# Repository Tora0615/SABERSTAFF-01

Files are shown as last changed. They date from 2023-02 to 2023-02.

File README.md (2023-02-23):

# SABERSTAFF-01

利用 attiny 85 與 433 mhz 無線收發模組製作的 ARGB 表演用光棍，解決不同裝置與電腦間的同步問題，實現了配合音樂節奏的卡點燈光表演。

The ARGB light rod made with attiny85 and 433 mhz wireless module. It solves the synchronization problem (e.g. music doesn't match the light) between different devices and computers. This made it can perform light show perfectly with music rhythm.

# Structure and how it work

```
--- PC ---

1. When Press the run button 
   |----> 2. Countdown ----> 7. Play music (Light Show will start at the same time)
   |----> 2. send reset signal via serial ----> Arduino nano + 433 mHz send module
                                                                    |
                                                                    |--> 3. send reset signal

--- SABERSTAFF ---

|---| 5. Self Reboot
|   |
|   ∨
-- attiny 85 <------- 433 mHz receive module (4. send a reset signal when receive data)
    |
    ∨
    6. Countdown
    |
    ∨
    7. Start the Light Show (Music will start at the same time)

```

# Design
## Hardware
### Schematic
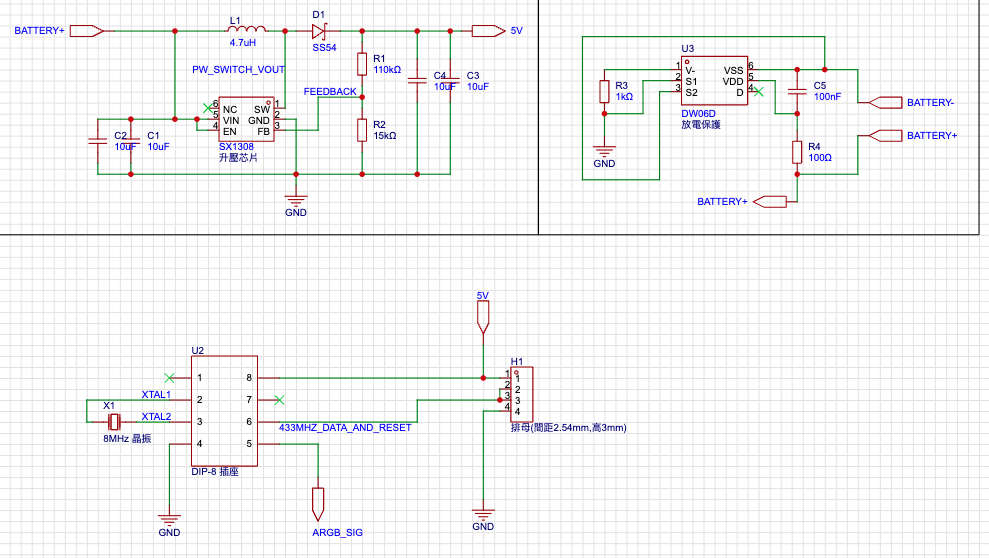
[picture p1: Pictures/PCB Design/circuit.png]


### PCB Design in 2D
<p float="left">
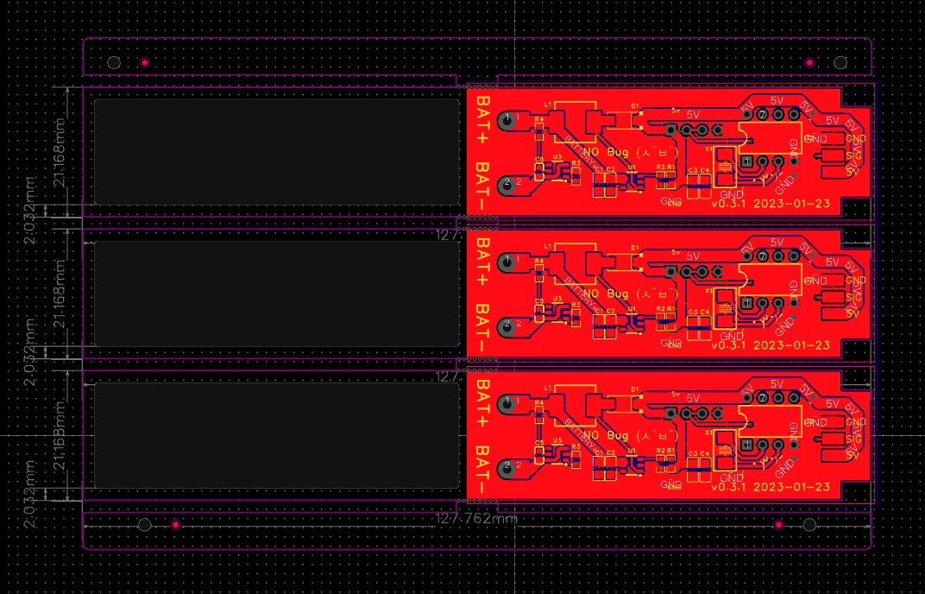
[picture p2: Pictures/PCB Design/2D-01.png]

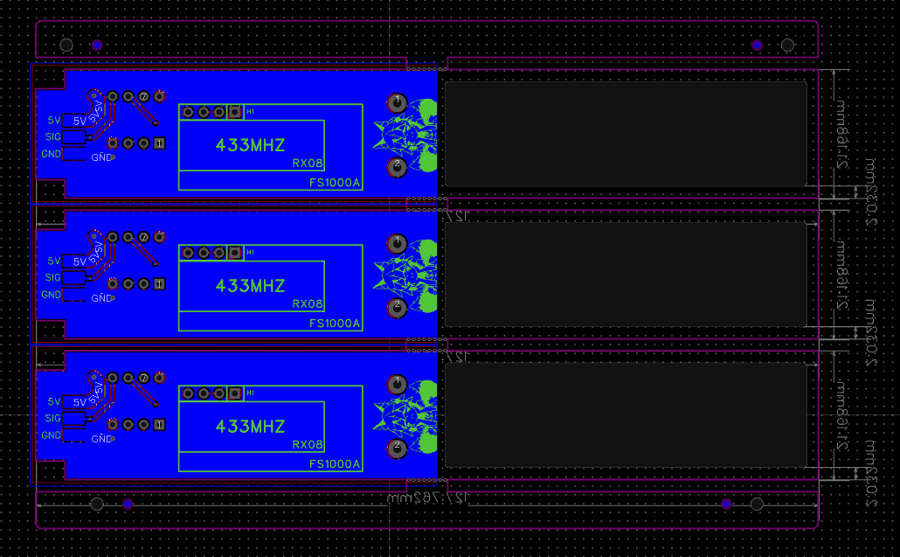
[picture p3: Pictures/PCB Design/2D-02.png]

</p>

### PCB Design in 3D
<p float="left">
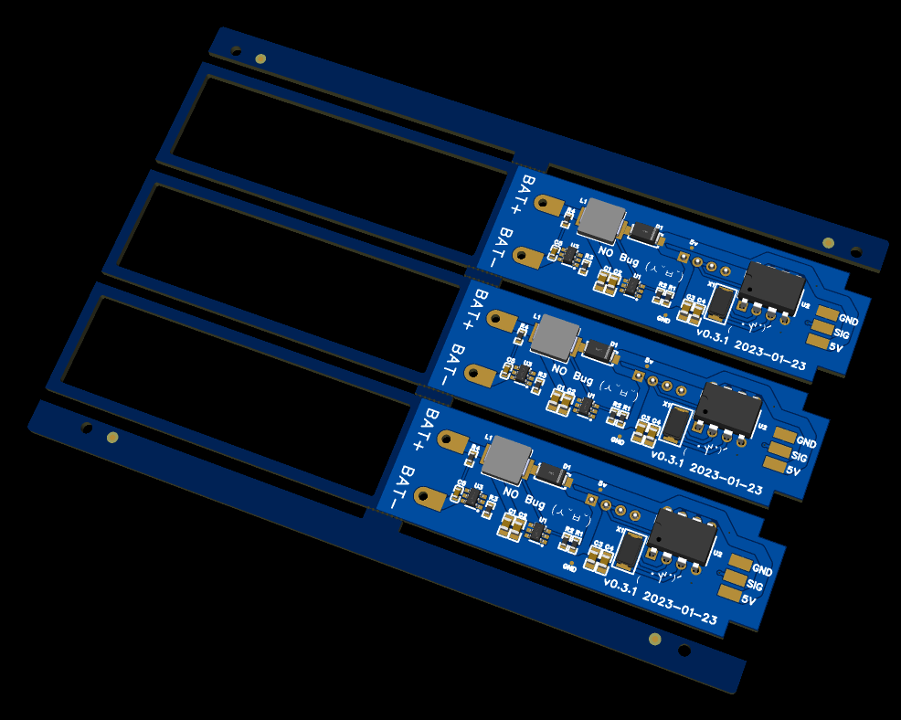
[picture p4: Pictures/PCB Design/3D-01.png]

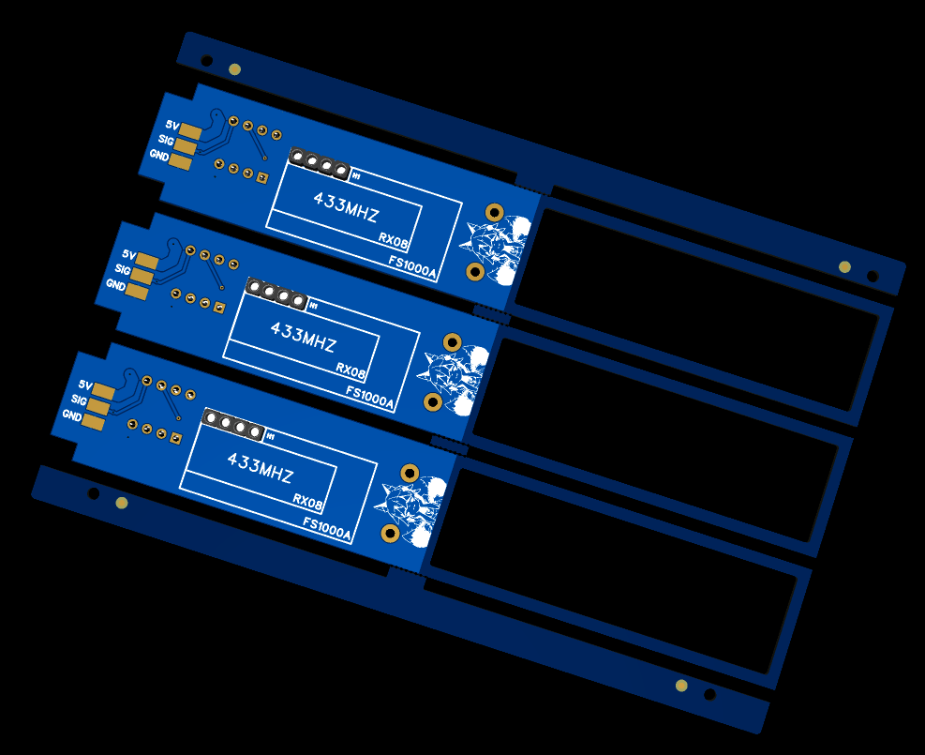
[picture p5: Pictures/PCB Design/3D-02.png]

</p>

### Real PCB 
<p float="left">
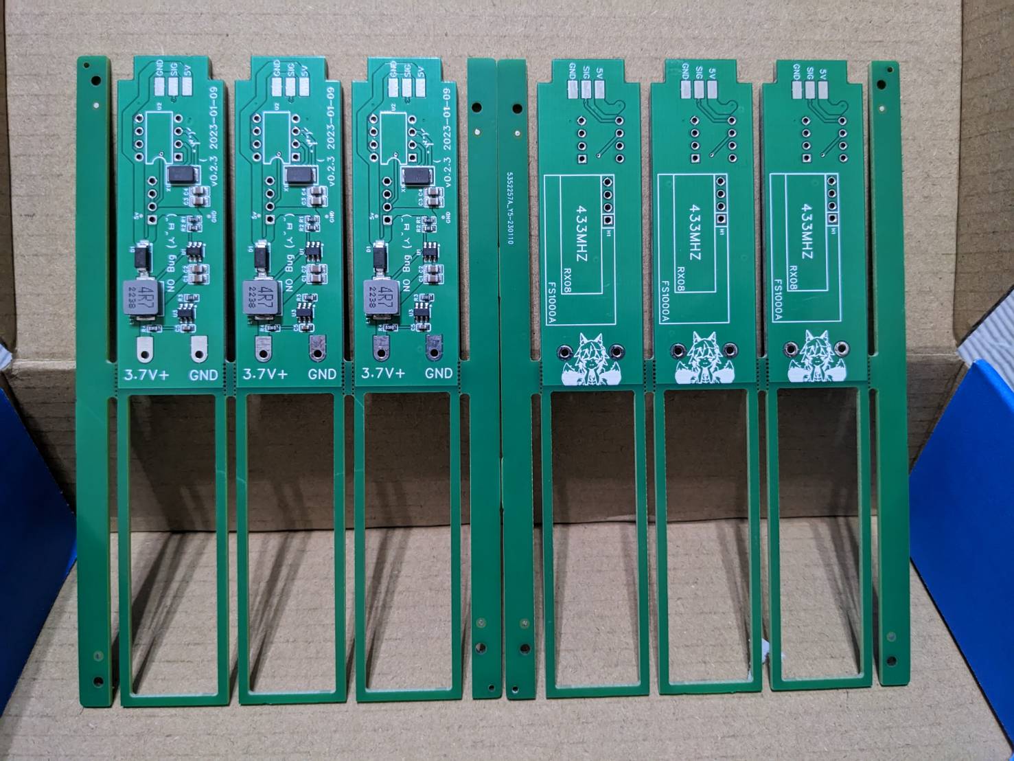
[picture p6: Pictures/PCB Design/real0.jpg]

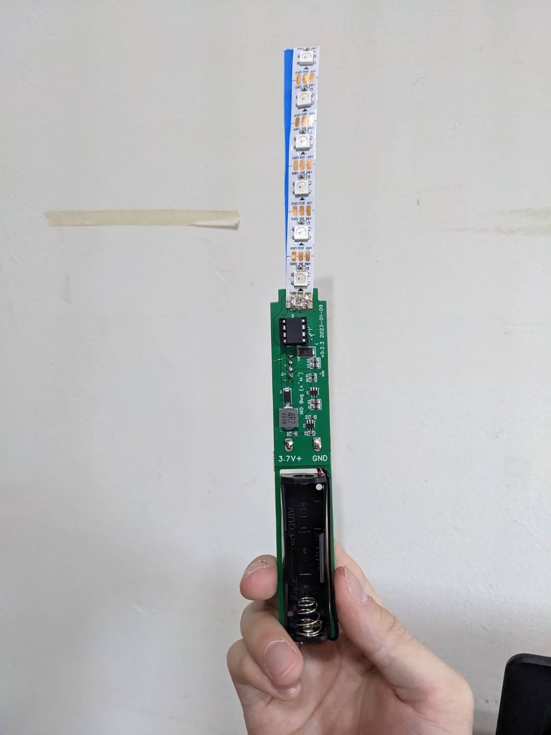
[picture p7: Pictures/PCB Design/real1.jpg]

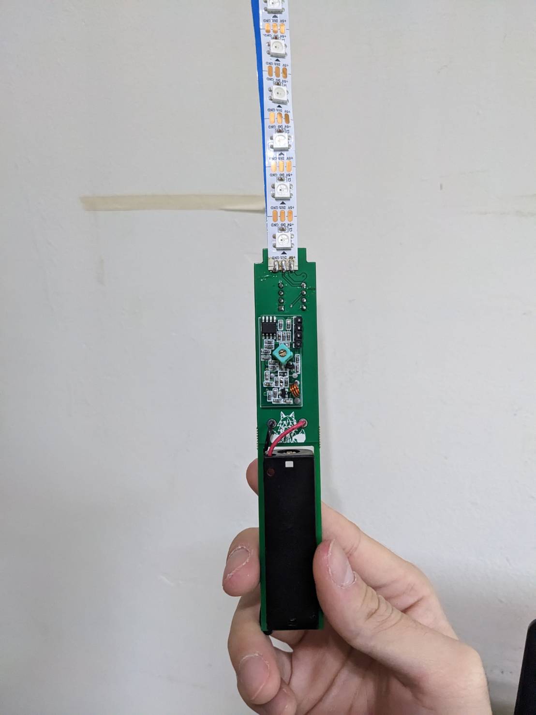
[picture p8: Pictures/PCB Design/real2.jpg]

</p>

### The finished product

fire

## Software

* Folder - PcControlArduino
  * python_control_arduino.py - control arduino via serial and control music playing at the same time.
* Folder - 433mhzDataSender_nano_ver
  * 433mhzDataSender_nano_ver.ino - the sender's code
* Folder - v1.3_simple_attiny_ver
  * v1.3_simple_attiny_ver.ino - main code of the rod, include self-reboot and how to recieve data.
  * music_data.h - can set delay_time, what style you like and how long the style will persist.
  * others - light sytle library and relative codes.

# Demo
 

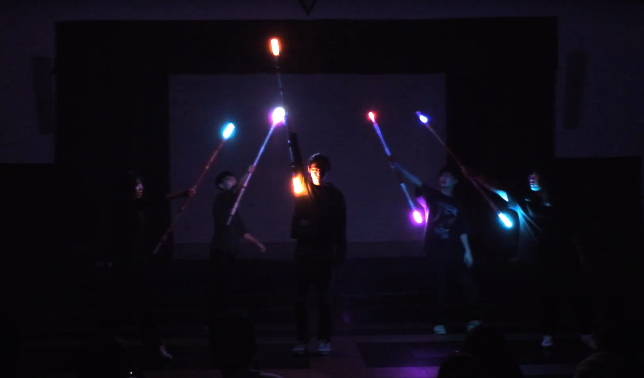
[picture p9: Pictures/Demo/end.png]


Full video :

https://youtu.be/G6jGiNdFs2k

# Where the dream begins...

Before I made the first verison of light rod, we use glow stick in the light show. Glow stick is heavy, expensive and not bright enough. To slove these problems, I decided to invent a thing that can do better and have many style. So here it comes.

In 2020, the first design was born. It made up of metal rod, plastic bottle and lots of items. It is bright enough, have many light style , but can't sychronize with each other. This made the light a little bit messy. Soon, because deadline is coming, this issue had been postponed.

Although the orignal design is beautiful, it is actually heavy and fragile. Often, I need to spend a lot of time to fix it. So the new design is needed. Pictures below is the orignal verion.

### The First design
<p float="left">
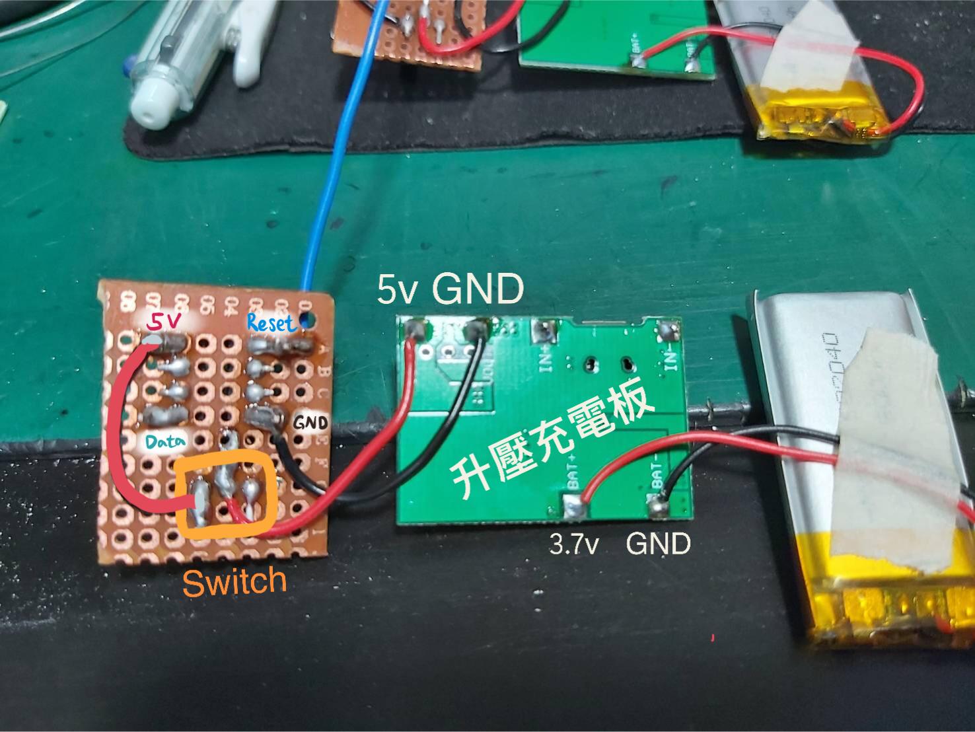
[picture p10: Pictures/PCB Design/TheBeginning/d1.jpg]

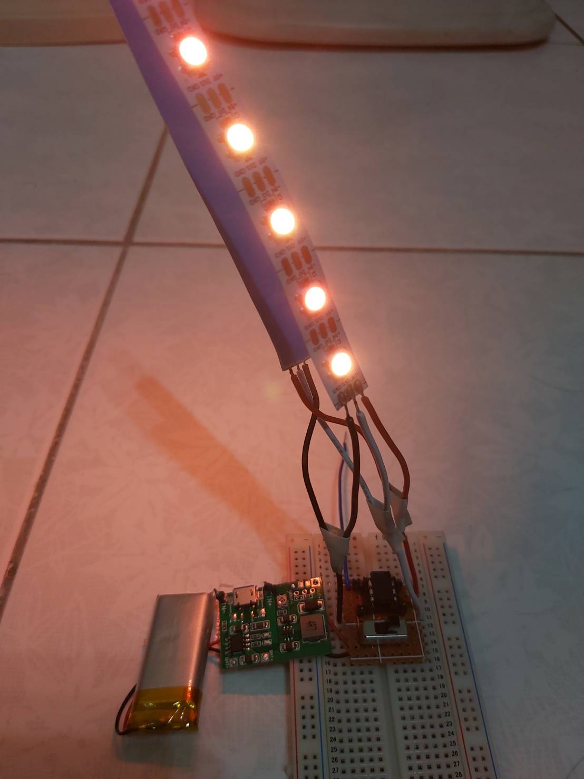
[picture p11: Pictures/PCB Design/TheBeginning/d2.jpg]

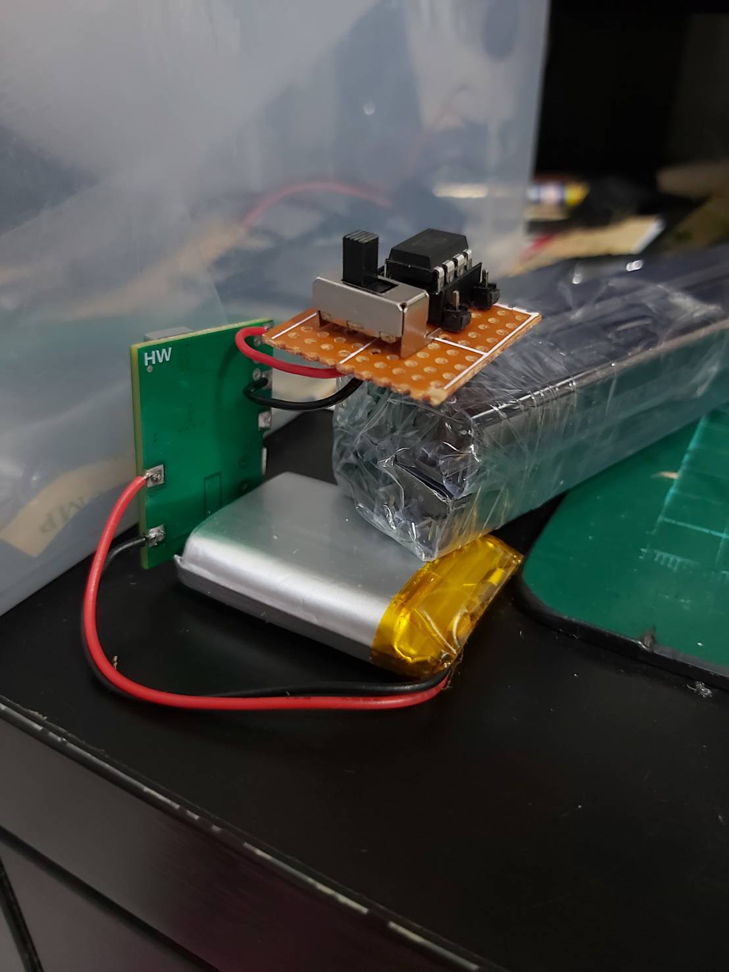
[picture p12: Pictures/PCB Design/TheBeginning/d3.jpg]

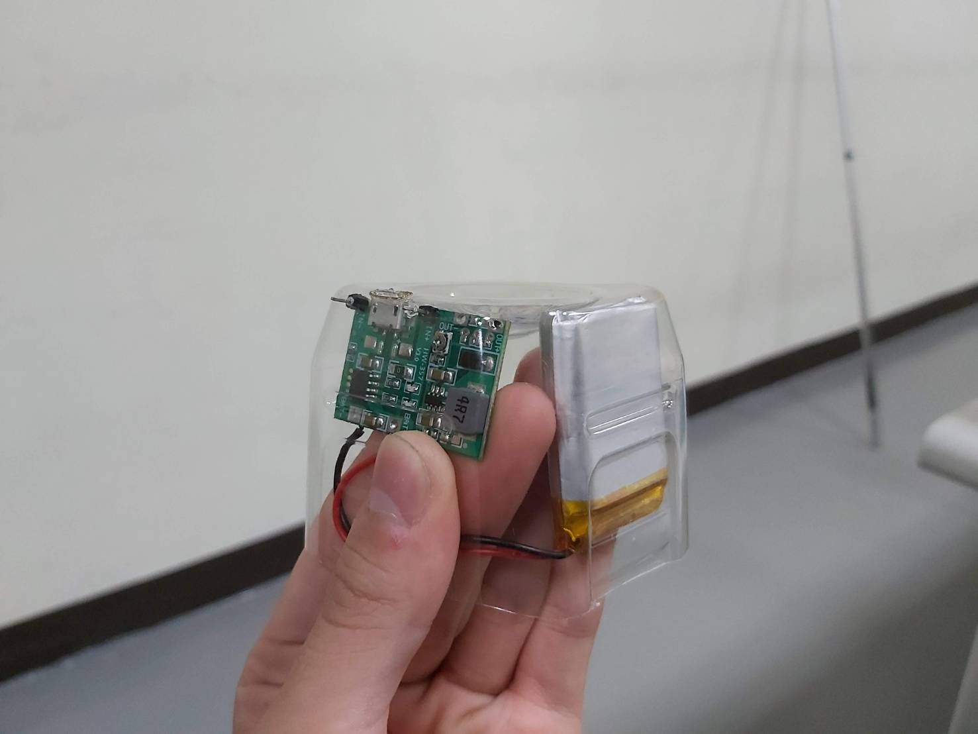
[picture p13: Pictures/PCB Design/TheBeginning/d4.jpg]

</p>

### The finished product
<p float="left">
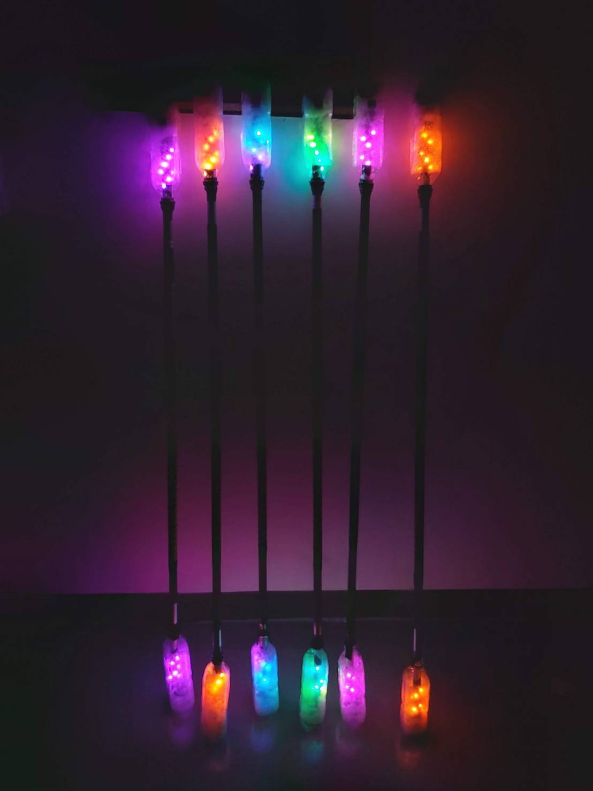
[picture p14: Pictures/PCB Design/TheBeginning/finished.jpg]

</p>

### The Show 
<p float="left">
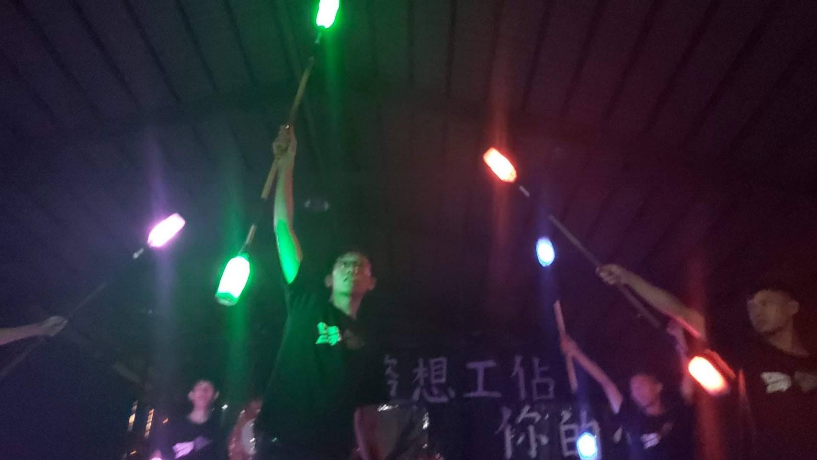
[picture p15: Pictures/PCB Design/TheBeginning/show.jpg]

</p>

### How it broke
<p float="left">
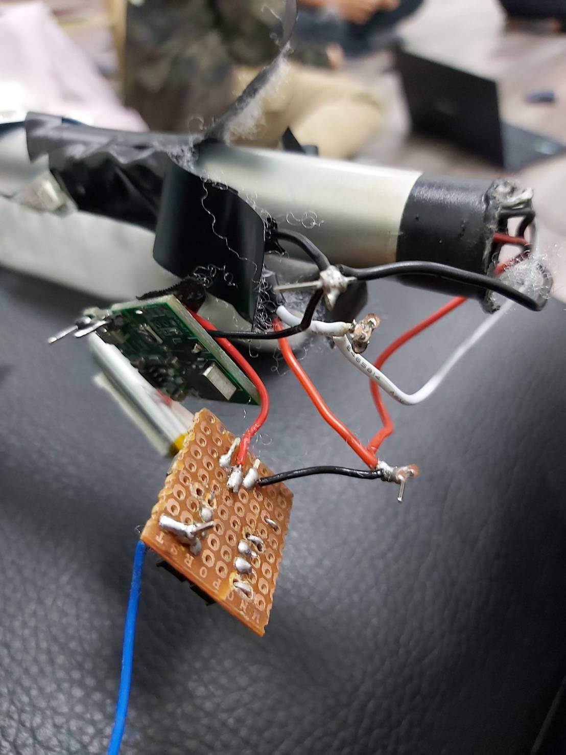
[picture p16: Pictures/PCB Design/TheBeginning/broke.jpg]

</p>

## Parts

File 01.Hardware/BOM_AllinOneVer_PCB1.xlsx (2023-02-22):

No. | Quantity | Comment | Designator | Footprint | Value | Manufacturer Part | Manufacturer | Supplier Part | Supplier | Pins | LCSC Stock | LCSC Price | JLCPCB Stock | JLCPCB Price
1 | 4 | 10uF | C1,C2,C3,C4 | C0805 | 10uF | C2012X5R1V106MT0J0E | TDK | C342723 | LCSC | 2 | 6985 | 0.2241 | 3012 | 1.408
2 | 1 | 100nF | C5 | C0603 | 100nF | 0603F104Z500CT | Walsin(华新科) | C83060 | LCSC | 2 | 894500 | 0.0024 | 638021 | 0.0148
3 | 1 | SS54 | D1 | SMA_L4.4-W2.8-LS5.4-R-RD |  | SS54 | MDD | C22452 | LCSC | 2 |  |  | 322125 | 0.295
4 | 1 | MF254V-11-04-0743 | H1 | HDR-TH_4P-P2.54-V-F-3 |  | MF254V-11-04-0743 | XFCN(兴飞) | C2889986 | LCSC | 4 | 125 | 0.1084 | 3 | 0.681
5 | 1 | 4.7uH | L1 | IND-SMD_L6.6-W6.6-LS7.3 | 4.7uH | MCS0630-4R7MN2 | PSA(信昌电陶) | C385253 | LCSC | 2 | 2285 | 0.0798 | 596 | 0.501
6 | 1 | 110kΩ | R1 | R0603 | 110kΩ | RC0603JR-07110KL | YAGEO(国巨) | C141267 | LCSC | 2 | 8900 | 0.0010 | 5399 | 0.00598
7 | 1 | 0603WAF1502T5E | R2 | R0603 | 15kΩ | 0603WAF1502T5E | UNI-ROYAL(厚声) | C22809 | LCSC | 2 |  |  | 703939 | 0.00652
8 | 1 | 1kΩ | R3 | R0603 | 1kΩ | 0603WAF1001T5E | UNI-ROYAL(厚声) | C21190 | LCSC | 2 |  |  | 16180750 | 0.00358
9 | 1 | 100Ω | R4 | R0603 | 100Ω | RC0603FR-07100RL | YAGEO(国巨) | C105588 | LCSC | 2 | 5814930 | 0.0009 | 2286920 | 0.00548
10 | 1 | SX1308 | U1 | SOT-23-6_L2.9-W1.6-P0.95-LS2.8-BR |  | SX1308 | SX(硕芯科技) | C78162 | LCSC | 6 | 59160 | 0.1810 | 48107 | 1.138
11 | 1 | DS1009-08AT1NX-0A2 | U2 | DIP-8_L10.0-W6.5-P2.54-LS7.6-BL |  | DS1009-08AT1NX-0A2 | CONNFLY | C72124 | LCSC | 8 |  |  | 3 | 0.184
12 | 1 | DW06D | U3 | SOT-23-6_L2.9-W1.6-P0.95-LS2.8-BR |  | DW06D | FM(富满) | C82123 | LCSC | 6 |  |  | 784 | 0.42
13 | 1 | 8MHz | X1 | OSC-SMD_L5.0-W3.2 | 8MHz | TAXM8M2QLFCDT1T | TAE(雅晶鑫) | C122522 | LCSC | 2 | 114835 | 0.1872 | 42914 | 1.176

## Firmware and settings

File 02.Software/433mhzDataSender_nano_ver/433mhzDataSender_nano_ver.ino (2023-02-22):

/* attiny 不能用，不然是最完美的*/
/*
#include <RH_ASK.h>
#include <SPI.h> // Not actually used but needed to compile

RH_ASK driver(2000,11,6);
const char *send_reset = "reset";

void setup() {
  pinMode(5, INPUT);  //3.3v -> D5
  pinMode(LED_BUILTIN, OUTPUT);
  if (!driver.init()){
        digitalWrite(LED_BUILTIN, HIGH);   // turn the LED on (HIGH is the voltage level)
        delay(10000); 
      }
  
  }

void loop() {
  if ( digitalRead(5) == LOW ) {
    driver.send((uint8_t *)send_reset, strlen(send_reset));
    driver.waitPacketSent();

    //Serial.println("sent_reset");
      digitalWrite(LED_BUILTIN, HIGH);   // turn the LED on (HIGH is the voltage level)
      delay(3000);                       // wait for a second
      digitalWrite(LED_BUILTIN, LOW);    // turn the LED off by making the voltage LOW
      delay(3000);     
  }
//  while(1){
//    
//  }
}

*/

/*
// 無法發送
#include <VirtualWire.h>
uint8_t send_reset[5] = {'r','e','s','e','t'};

void setup() {
  pinMode(5, INPUT);  //3.3v -> D5
  pinMode(LED_BUILTIN, OUTPUT);

  //vw_set_ptt_inverted(true);
  vw_set_tx_pin(5);
  vw_setup(2000);
  }

void loop() {
  if ( digitalRead(5) == LOW ) {
    digitalWrite(LED_BUILTIN, HIGH);   // turn the LED on (HIGH is the voltage level)
    delay(3000);  
    
    vw_send((uint8_t *)send_reset, strlen(send_reset));
    vw_wait_tx();
    
    digitalWrite(LED_BUILTIN, LOW);    // turn the LED off by making the voltage LOW
    delay(3000);     
  }
}
*/


#include "ManchesterRF.h" //https://github.com/cano64/ManchesterRF
#define TX_PIN 6 //any pin can transmit

ManchesterRF rf(MAN_600); 

uint8_t data = 1;  // meaning is to reset
String got_from_serial;

void setup() {
  //pinMode(LED_BUILTIN, OUTPUT);  
  rf.TXInit(TX_PIN);
  Serial.begin(9600);
}

void loop() {
  if (Serial.available()) {
    got_from_serial = Serial.readStringUntil('\n');  // 讀取傳入的字串直到"\n"結尾
    if(got_from_serial == "reset!"){
      rf.transmitByte(data);
      }
  }

//  if ( digitalRead(5) == LOW ) {
//      digitalWrite(LED_BUILTIN, HIGH);   // turn the LED on (HIGH is the voltage level)
//      delay(500); 
//      rf.transmitByte(data);
//      digitalWrite(LED_BUILTIN, LOW);    // turn the LED off by making the voltage LOW
//      delay(500);   
//    }
}

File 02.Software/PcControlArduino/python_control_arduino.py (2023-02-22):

# -*- coding: utf-8 -*-
"""
Created on Wed Jan 11 01:00:01 2023

@author: Arthur
"""

import serial #need to install pyserial
import time
from playsound import playsound  ## pip install playsound==1.2.2

mp3file = "Beautiful Now.mp3"
delayTime = 29.8

COM_PORT = 'COM3'  # 請自行修改序列埠名稱
BAUD_RATES = 9600
ser = serial.Serial(COM_PORT, BAUD_RATES)
time.sleep(1) #open serial will let arduino reboot, need to wait it.  every arduino's reboot time is different...



# try many times guarantee it can send seccessfully
a = time.time()
for i in range(50):
    ser.write(b'reset!\n')
ser.close()
#print(time.time()-a)


print("默默倒數"+ str(delayTime) +"秒 開始")
time.sleep(delayTime)
    
print("開始撥放")    
playsound(mp3file)


'''
while True:
    ser.write(b'reset!\n')
    time.sleep(10)
'''

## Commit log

2023-02-22 init : update all items
    [BOM_AllinOneVer_PCB1.xlsx, PickAndPlace_PCB1.xlsx]
2023-02-22 doc : change somethings
    [Drill_NPTH_Through.DRL, Drill_PTH_Through.DRL, Drill_PTH_Through_Via.DRL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]
